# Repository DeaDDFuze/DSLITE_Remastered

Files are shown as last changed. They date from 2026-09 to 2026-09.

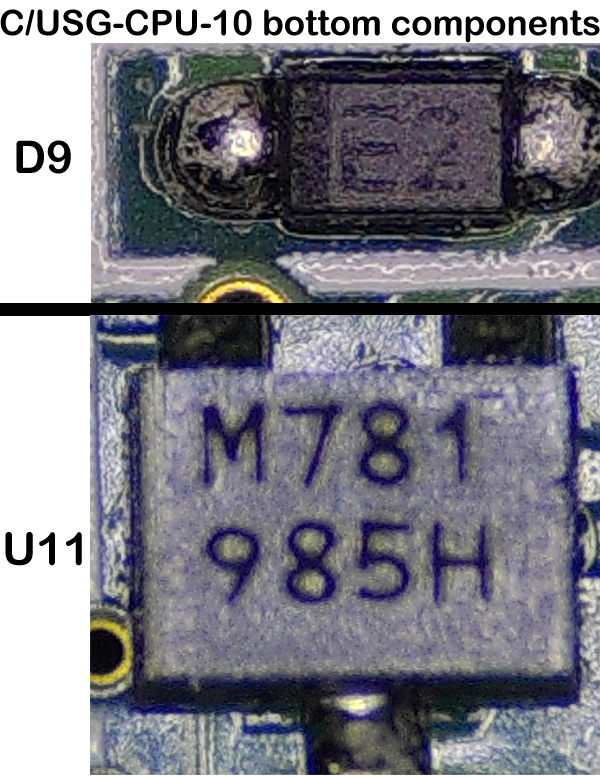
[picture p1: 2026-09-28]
docs/reverse-engineering/C-USG-CPU-10 components bottom.jpg

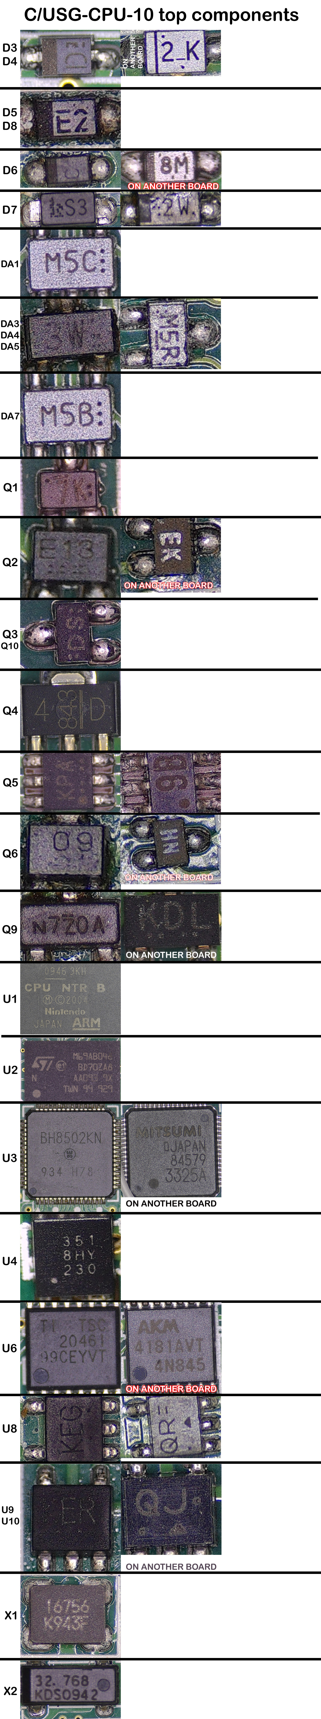
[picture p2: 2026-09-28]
docs/reverse-engineering/C-USG-CPU-10 components top.jpg

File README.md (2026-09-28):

# DSLITE_Remastered

> A modern hardware rework of the Nintendo DS Lite.

**DSLITE_Remastered** is an experimental hardware engineering project aiming to recreate and modernize the Nintendo DS Lite while preserving compatibility with the original console, cartridges, controls and overall form factor.

The goal is not to emulate a Nintendo DS on a modern computer.

The goal is to understand the original hardware, reverse-engineer it where necessary, redesign selected parts of the electronics, and progressively build a **modernized DS Lite around the original architecture**.

---

## Project goals

DSLITE_Remastered explores several areas of console hardware modernization:

- Reverse engineering of the Nintendo DS Lite motherboard
- Recreation of schematics in KiCad
- PCB analysis and eventual PCB redesign
- Replacement of ageing or obsolete components
- USB-C charging
- Modern battery and charging circuitry
- Improved power management
- Modern replacement displays
- Experimental display scaling / image processing
- Replacement shells and mechanical parts
- 3D CAD reconstruction of the console
- Improved repairability
- Hardware documentation
- Community-friendly component libraries

The project will remain modular so individual modifications can potentially be reproduced independently.

---

## Project philosophy

The idea behind DSLITE_Remastered is simple:

**repair, understand, reproduce, improve.**

Rather than replacing the entire console with a Raspberry Pi or an emulator, this project attempts to retain as much of the original Nintendo DS architecture as possible.

Whenever possible, the project will favor:

- original hardware compatibility;
- measurable and documented modifications;
- replaceable components;
- open design files;
- commonly available parts;
- reproducible modifications;
- preservation of the original console's behaviour.

Some parts of the project will necessarily remain experimental.

---

## Planned architecture

The long-term project may include several independent hardware modules.

### Main motherboard

Reverse engineering and recreation of the Nintendo DS Lite motherboard.

Current reference board:

`USG-CPU-10`

Objectives:

- reproduce the original schematic;
- identify component functions;
- document power rails;
- document buses and signals;
- recreate footprints;
- compare component revisions;
- prepare a possible redesigned motherboard.

---

### Power system

Potential improvements:

- USB-C connector;
- USB-C charging;
- modern Li-ion / Li-Po battery support;
- improved battery protection;
- improved charging controller;
- voltage monitoring;
- replaceable battery design.

USB Power Delivery is not currently required for the console but may be investigated for future accessories or docking concepts.

---

### Displays

One of the major experimental areas of the project.

Possible directions include:

- modern IPS LCD replacements;
- custom LCD interface boards;
- OLED experimentation;
- improved brightness;
- improved viewing angles;
- replacement backlight circuitry.

The native Nintendo DS resolution remains:

**256 × 192 pixels per screen**

A future experimental display controller may investigate integer scaling or real-time upscaling to higher-resolution panels.

---

## DS Remastered display concept

A more experimental branch of the project explores the concept of a **"DS Remastered" display pipeline**.

Instead of modifying the game software, a dedicated video-processing circuit could intercept the original display signal and process it before sending it to a modern panel.

Conceptually:

```text
Nintendo DS GPU
      │
      ▼
Original display signal
      │
      ▼
Video capture / interface
      │
      ▼
FPGA / video processor
      │
      ├── Integer scaling
      ├── Filtering
      ├── Pixel reconstruction
      └── Experimental upscaling
      │
      ▼
Modern LCD / OLED panel
```

The first realistic objective would be **clean integer scaling**, not AI-based reconstruction.

More advanced processing may be investigated later.

---

## Mechanical redesign

The mechanical side of the project will be developed primarily using **Fusion 360**.

Possible work includes:

- recreation of the DS Lite shell;
- internal mounting points;
- USB-C modifications;
- display adapters;
- replacement hinge mechanisms;
- battery compartment redesign;
- custom shells;
- prototype PCBs;
- 3D printable replacement parts.

KiCad remains the primary tool for electronic design.

---

## Software used

### Electronics

- KiCad
- SPICE simulation where appropriate
- Datasheets
- Multimeter
- Logic analyser
- Oscilloscope

### Mechanical design

- Autodesk Fusion 360
- Mesh / STEP / STL tools
- 3D printing

### Development / documentation

- Git
- GitHub
- Linux
- Markdown
- Python

---

## Repository structure

The repository will progressively follow a structure similar to:

```text
DSLITE_Remastered/
│
├── README.md
├── LICENSE
│
├── docs/
│   ├── architecture/
│   ├── reverse-engineering/
│   ├── measurements/
│   └── research/
│
├── datasheets/
│
├── schematic/
│   ├── original/
│   └── remastered/
│
├── pcb/
│   ├── original/
│   └── remastered/
│
├── libraries/
│   ├── symbols/
│   ├── footprints/
│   └── 3dmodels/
│
├── mechanical/
│   ├── shell/
│   ├── screen/
│   └── usb-c/
│
├── firmware/
│
├── tools/
│
└── references/
```

This structure may change as the project evolves.

---

## Current project status

**Status: Research / Reverse Engineering**

Current work focuses on:

- collecting DS Lite motherboard documentation;
- analysing the `USG-CPU-10` board revision;
- identifying components;
- collecting datasheets;
- reconstructing schematics;
- creating reusable KiCad symbols and footprints;
- preparing a clean Git repository structure.

No complete replacement motherboard exists yet.

---

## Roadmap

### Phase 1 — Documentation

- [ ] Photograph and document the motherboard
- [ ] Identify major ICs
- [ ] Identify passive components
- [ ] Collect datasheets
- [ ] Document test points
- [ ] Document connectors
- [ ] Map power rails

### Phase 2 — Schematic reconstruction

- [ ] Recreate `USG-CPU-10` schematics
- [ ] Verify connections
- [ ] Create missing KiCad symbols
- [ ] Create missing footprints
- [ ] Compare board revisions

### Phase 3 — PCB reconstruction

- [ ] Recreate PCB outline
- [ ] Position major components
- [ ] Reconstruct routing
- [ ] Validate dimensions
- [ ] Generate 3D PCB model

### Phase 4 — Modernization

- [ ] USB-C charging
- [ ] Modern battery circuitry
- [ ] Modern replacement displays
- [ ] Improved power circuitry
- [ ] Replacement shell design

### Phase 5 — DS Remastered experiments

- [ ] Capture original LCD signals
- [ ] Characterize timing
- [ ] Prototype FPGA display interface
- [ ] Integer-scale DS output
- [ ] Test higher-resolution panels
- [ ] Investigate image enhancement

### Phase 6 — Prototype

- [ ] Manufacture prototype PCBs
- [ ] Assemble board
- [ ] Power validation
- [ ] Boot testing
- [ ] Cartridge testing
- [ ] Touchscreen testing
- [ ] Wireless testing
- [ ] Long-term reliability testing

---

## Reverse engineering notes

All measurements and reverse-engineering information should be documented whenever possible.

Useful information includes:

```text
Component reference
Manufacturer
Part number
Package
Measured value
Connected signals
Voltage
Frequency
Datasheet
Board location
Notes
```

This repository should progressively become both a development repository and a technical reference for DS Lite hardware.

---

## KiCad libraries

One objective of the project is to create a reusable local KiCad library for DS Lite components.

Example:

```text
libraries/
├── symbols/
│   └── DSLITE_Remastered.kicad_sym
│
├── footprints/
│   └── DSLITE_Remastered.pretty/
│
└── 3dmodels/
    ├── STEP/
    └── WRL/
```

Components should preferably include:

- symbol;
- footprint;
- datasheet reference;
- manufacturer part number;
- package;
- pin description;
- 3D model when available.

---

## Contributions

Contributions are welcome.

Useful contributions include:

- board photographs;
- high-resolution scans;
- component identification;
- datasheets;
- PCB measurements;
- schematics;
- KiCad symbols;
- KiCad footprints;
- 3D models;
- electrical measurements;
- compatible replacement components;
- repair documentation.

Please document the source of technical information whenever possible.

---

## Disclaimer

DSLITE_Remastered is an independent, unofficial hardware research project.

Nintendo, Nintendo DS, Nintendo DS Lite and related trademarks are property of Nintendo and their respective owners.

This project is not affiliated with, endorsed by, or sponsored by Nintendo.

The repository is intended for:

- hardware research;
- repair;
- preservation;
- reverse engineering;
- education;
- experimentation.

No proprietary Nintendo software, firmware, ROMs or copyrighted game assets should be distributed through this repository.

---

## License

The final licensing model has not yet been selected.

Because the project may contain hardware designs, documentation and software, separate licenses may eventually be used for each category.

Possible choices include:

- CERN Open Hardware Licence for PCB and hardware designs
- GPL or MIT for software and tools
- Creative Commons for documentation

---

## Project name

**DSLITE_Remastered**

Experimental Nintendo DS Lite hardware modernization and preservation project.

```text
Original hardware.
Modern components.
Same DS.
```

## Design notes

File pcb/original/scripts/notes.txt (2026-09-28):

2 vias are missing from the vdd plane. but they are present on the vias script. one is near a hole in the left side of the board. and the other is close to the vdd1.2 plane (where the scan is scratched).

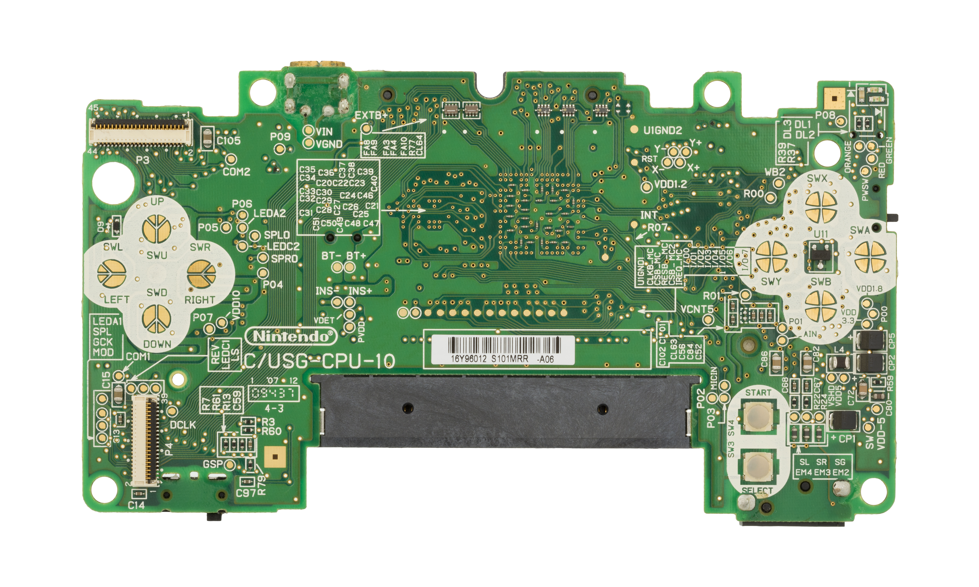
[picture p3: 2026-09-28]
docs/reverse-engineering/wikipedia bottom.jpg

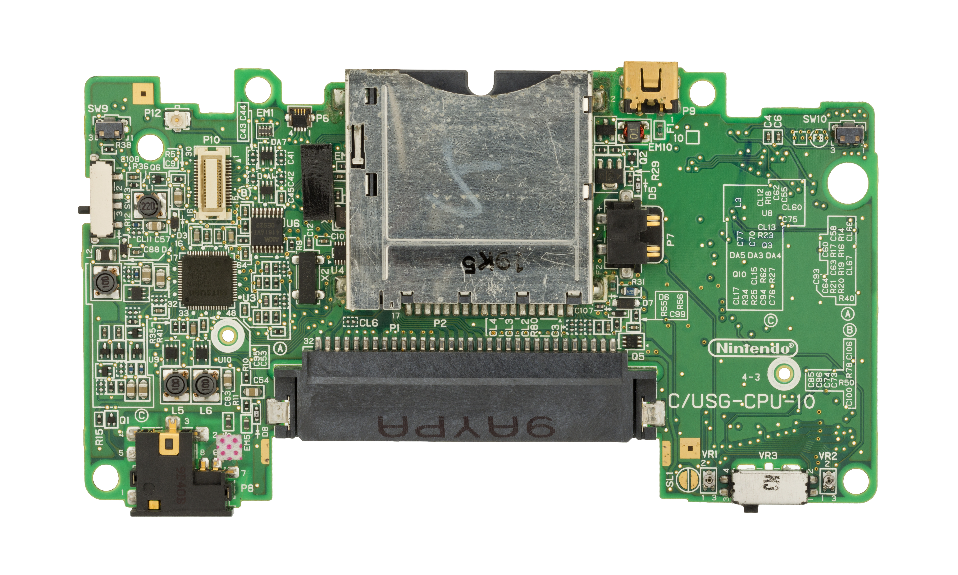
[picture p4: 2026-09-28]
docs/reverse-engineering/wikipedia top.jpg

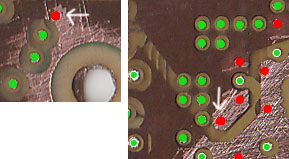
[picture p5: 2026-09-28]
pcb/original/scripts/notes.jpg

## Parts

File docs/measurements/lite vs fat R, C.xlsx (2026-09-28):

Lite(C/USG-CPU-10) | Fat(C/NTR-CPU-10)
TOP
R31-(MARKED R634) | R31=(MARKED R910) |  | between INS+ and INS-
R36-100K | R36=198.2K |  | power switch pullup
.--- | R51=675R
R78-1K | .---
R80-100R | .---
R60-2.2K | R60=2.7K | lite is on the bottom | VR1 to gnd (top screen)
R61-2.2K | R61=2.7K | lite is on the bottom | VR2 to gnd (bottom screen)
.--- | R63=20K
.--- | R66=200k
.--- | R67=100K
.--- | R68=55.9K
.--- | R69=5K
.--- | R70=5K
C55-11UF | C55=5.8UF | fat is on the bottom | B+ to gnd
C52-100NF | C52=1.2UF | lite is on the bottom | PMIC38 (AIN)
C56-100NF | C56=1.2UF | lite is on the bottom | B+ to gnd
.--- | C65=5.8UF
C73-5UF | C73=10UF |  | EXTB+ to gnd
.--- | C78=1.2UF
C83-10UF | C83=5.8UF |  | B+ (LEDA1 area)
.--- | C87=5.8UF
C106-1.1NF | .---
C107-0.13NF | .---
C108-100NF | .---
BOTTOM
R3-32.8K | R3=20K |  | VR1 to VDD5 (top screen)
R7-32.7K | R7=20K |  | VR2 to VDD5 (bottom screen)
.--- | R26=510K
.--- | R32=10R
.--- | R33=100K
.--- | R45=100K
.--- | R46=100K
.--- | R47=100K
.--- | R48=200K
.--- | R49=200K
.--- | R53=100R
.--- | R54=100R
R79-10K | .---
.--- | C8=100NF
.--- | C35=100NF
.--- | C61=5.8UF
.--- | C66=100NF
.--- | C71=2.4UF
.--- | C79=100NF
.--- | C81=2.4UF
.--- | C89=2.5UF
.--- | C90=2.4UF
.--- | C91=10UF
.--- | C92=100NF
C101-100NF | .---
C102-100NF | .---
C105-11UF | .---

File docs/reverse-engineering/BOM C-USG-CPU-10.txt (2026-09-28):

The donor board was in perfect working condition. C/USG-CPU-10

TOP COMPONENTS (THE SIDE WITH THE CPU)
R1-1.5M
R2-2.2K
R5-100K
R9-57.2K
R10-2.2K
R11-2.2K
R12-0R???
R14-47K
R15-1M
R16-47K
R17-47K
R18-0R???
R19-47K
R20-46.2K
R21-46.7K
R23-0R???
R25-500K
R27-0.8R
R28-676R
R29-500K
R30-240R
R31-0R??? (MARKED R634)
R34-1M
R35-33.3R
R36-100K
R38-1.3K
R40-10K
R41-33.3R
R50-10R
R55-200K
R56-100K
R62-0.8R
R65-55.2R
R78-1K
R80-100R
C1-TO LOW TO MEASURE
C2-TO LOW TO MEASURE
C3-1.1UF
C4-100NF
C5-1.1UF
C6-100NF
C9-10UF
C10-100NF
C11-100NF
C12-TO LOW TO MEASURE
C17-1.1UF
C45-1.1UF
C53-1UF
C54-11UF
C55-11UF
C57-23UF
C58-0.140NF
C60-0.56NF
C62-23UF
C63-0.135NF
C64-0.56NF
C70-100NF
C73-5UF
C74-1.1UF
C75-1.2UF
C76-10UF
C77-100NF
C83-10UF
C85-5UF
C88-100NF
C93-1.1UF
C94-10UF
C95-2.5UF
C96-100NF
C99-100NF
C100-100NF
C106-1.1NF
C107-0.13NF
C108-100NF
L1-0.02MH
L2-0.03MH
L3, L5, L6-0.01MH

cl2.3,4,5,6,9,11,12,13,15,17, 60,65,67,68 closed

BOTTOM COMPONENTS
R3-32.8K
R7-32.7K
R13-3K
R22-55.3R
R24-56R
R37-1.3K
R39-1.1K
R59-200K
R60-2.2K
R61-2.2K
R79-10K
C13-100NF
C14-100NF
C15-11UF
C52-100NF
C56-100NF
C59-100NF
C67-100NF
C68-100NF
C72-2.3UF
C80-1UF
C82-1UF
C84-100NF
C86-1UF
C97-100NF
C101-100NF
C102-100NF
C105-11UF
UNDER CPU: C20...C40, C46...C51 ALL ARE 100NF
CP1, CP2, CP5-100UF
L4-0.03MH

cl 63, 64 closed

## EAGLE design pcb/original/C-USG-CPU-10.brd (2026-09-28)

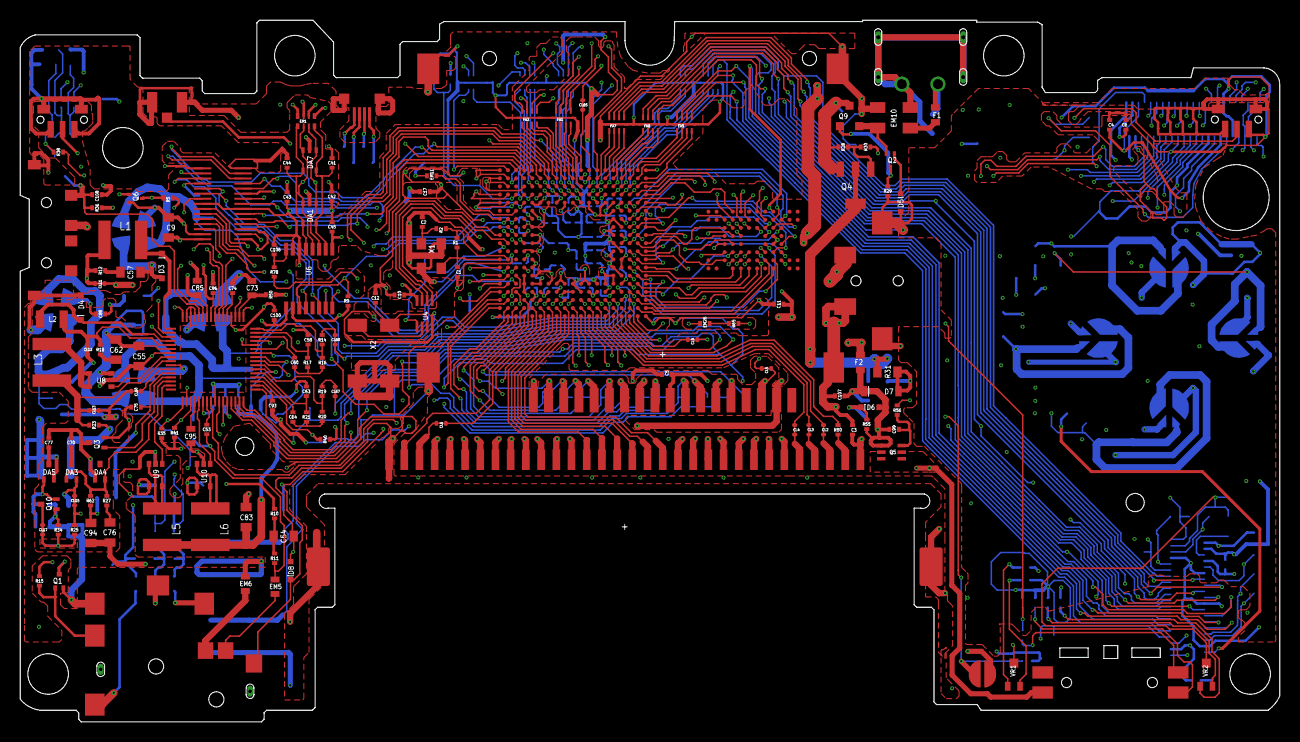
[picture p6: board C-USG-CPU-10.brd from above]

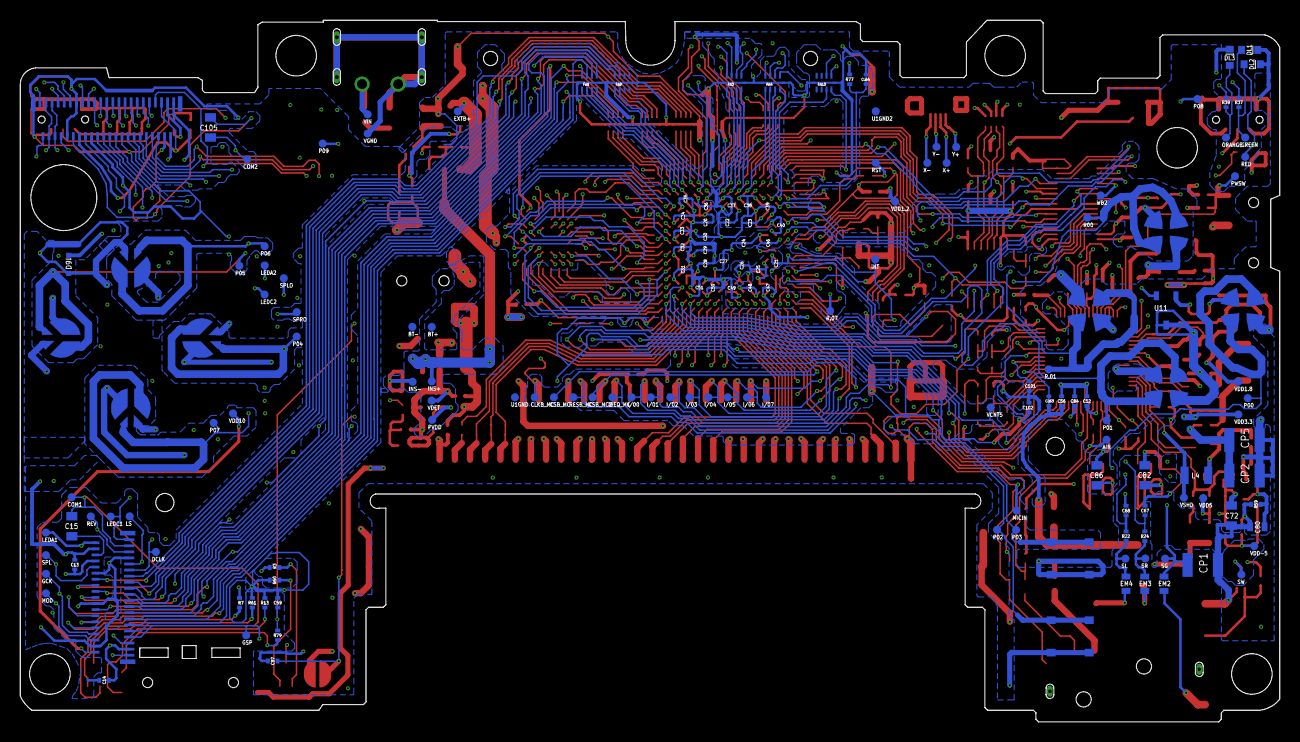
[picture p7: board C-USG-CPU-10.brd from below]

Board: 6 copper layers, 124.3 x 69.2 mm, 319 parts (164 on the bottom side), 328 nets.

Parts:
AIN: TP
BT+: TP
BT-: TP
BUT_A: BUT_ABXY; BUTTONSABXY
BUT_B: BUT_ABXY; BUTTONSABXY
BUT_L: SHOULDER_BUT
BUT_R: SHOULDER_BUT
BUT_X: BUT_ABXY; BUTTONSABXY
BUT_Y: BUT_ABXY; BUTTONSABXY
C1, C2, C3, C4, C5, C6, C10, C11, C12, C13, C14, C17, C41, C42, C43, C44, C45, C52, C53, C56, C58, C59, C60, C63, C64, C67, C68, C70, C74, C75, C77, C84, C88, C93, C96, C97, C99, C100, C101, C102, C106, C107, C108: C0402; 0402
C9, C15, C54, C55, C57, C62, C72, C76, C82, C83, C86, C94, C105: C0805; 0805
C20, C21, C22, C23, C24, C25, C26, C27, C28, C29, C30, C31, C32, C33, C34, C35, C36, C37, C38, C39, C40, C46, C47, C48, C49, C50, C51: C0201; 0201
C73, C80, C85, C95: C0603; 0603
CL2, CL3, CL4, CL5, CL6, CL9, CL11, CL12, CL13, CL15, CL17, CL60, CL63, CL64, CL65, CL67, CL68: CL; CL0402
CLKB_MC: TP
COM1, COM2: TP
CP1, CP2, CP5: CP
CSB_MC, CSB_MC2: TP
D3, D4: D3.4
D5, D9: D5
D6: D6
D7: D7
D8: D8
DA1: MA5J002D; DA
DA3, DA4, DA5: MA3SD29F
DA7: MA5J002E; DA
DCLK: TP
DL1, DL2, DL3: DL
DOWN: DPAD
EM1: FILTER_NETWORK
EM2, EM3, EM4, EM5, EM6: FILTER0603; 0603
EM10: EM10
EM11, EM26: FILTER; 0402
EXTB+: TP
F1, F2: FUSE
FA1, FA2, FA3, FA4, FA5, FA6, FA7, FA8, FA9, FA10: FA
GCK: TP
GREEN: TP
GSP: TP
I/00, I/01, I/02, I/03, I/04, I/05, I/06, I/07: TP
INS+: TP
INS-: TP
INT: TP
IREQ_MC: TP
L1, L3, L5, L6: INDUCTOR
L2, L4: INDUCTOR_SMALL
LEDA1, LEDA2: TP
LEDC1, LEDC2: TP
LEFT: DPAD
LS: TP
MICIN: TP
MOD: TP
ORANGE: TP
P00, P01, P02, P03, P04, P05, P06, P07, P08, P09: TP
P.1: GBASLOT; GBA
P.2: DSSLOT; DS
P.3: TOP_SCR+SPK
P.4: BOTTOM_SCREEN
P.6: TOUCH; P6
P.7: BAT
P.8: HEADPHONES
P.9: CHARGEPORT
P.10: DWM-W006; DWM--W006
P.12: MIC
PVDD: TP
PWSW: TP
Q1: Q1
Q2: DTA143ZM; SOT723
Q3, Q10: SSM3K16FS; Q3.10
Q4: 2SA2069; SOT89-3
Q5: SSM6J21TU; UF6
Q6: 2SC4244; SOT723
Q9: SSM3J14T; TO236
R00, R.01, R.07: TP
R1, R2, R3, R5, R7, R9, R10, R11, R12, R13, R14, R15, R16, R17, R18, R19, R20, R21, R22, R23, R24, R25, R27, R28, R29, R30, R34, R35, R36, R37, R38, R39, R40, R41, R50, R55, R56, R59, R60, R61, R62, R65, R77, R78, R79, R80: R0402; 0402
R31: R0805; 0805
RED: TP
RESB_MC: TP
REV: TP
RIGHT: DPAD
RST: TP
SELECT: BUTTON_SMALL
SG: TP
SL: TP
SL1: SL1
SPL: TP
SPLO: TP
SPRO: TP
SR: TP
START: BUTTON_SMALL
SW: TP
SW13: SWITCH
U1: NTR_CPU_B; CPU
U1GND, U1GND2: TP
U2: 82DBS02163C-70L; RAM
U3: MITSUMI_3325A
U4: RTC; TSSOP8
U6: TSC2046; TSSOP16
U8: SSM5G04TU; SOT-353F___(UFV)-M
U9, U10: SSM5H08TU; SOT-353F___(UFV)-M
U11: EM6781
UP: DPAD
VCNT5: TP
VDD1.2, VDD1.8, VDD3.3, VDD5, VDD10: TP
VDD-5: TP
VDET: TP
VGND: TP
VIN: TP
VR1, VR2: VR
VR3: VOLUME
VSHD: TP
WB2: TP
X1: X1
X2: X2
X+: TP
X-: TP
Y+: TP
Y-: TP

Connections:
A16: P.1.22, U1.G17
A17: P.1.23, U1.H17
A18: P.1.24, U1.I17
A19: P.1.25, U1.J17
A20: P.1.26, U1.K17
A21: P.1.27, U1.L17
A22: P.1.28, U1.M17
A23: P.1.29, U1.N17
AD0: P.1.6, U1.G18
AD1: P.1.7, U1.G19
AD2: P.1.8, U1.H18
AD3: P.1.9, U1.H19
AD4: P.1.10, U1.I18
AD5: P.1.11, U1.I19
AD6: P.1.12, U1.J18
AD7: P.1.13, U1.J19
AD8: P.1.14, U1.K18
AD9: P.1.15, U1.K19
AD10: P.1.16, U1.L18
AD11: P.1.17, U1.L19
AD12: P.1.18, U1.M18
AD13: P.1.19, U1.M19
AD14: P.1.20, U1.N18
AD15: P.1.21, U1.N19
AIN: AIN.P$1, C53.2, EM5.1, R11.2
AUX: R78.1, U3.40
B+: C55.1, C56.2, C83.1, CL63.1, CL63.2, L5.P$2, L6.P$2, Q5.1, Q5.2, Q5.5, Q5.6, U3.16, U3.19, U3.23, U3.55, U8.2, VR3.3
B.B0: FA6.1, P.4.22
B.B1: FA7.7, P.4.23
B.B2: FA7.5, P.4.24
B.B3: FA7.3, P.4.25
B.B4: FA7.1, P.4.26
B.B5: FA9.3, P.4.27
B.G0: FA8.7, P.4.15
B.G1: FA6.5, P.4.16
B.G2: FA6.7, P.4.17
B.G3: FA8.5, P.4.19
B.G4: FA9.1, P.4.20
B.G5: FA6.3, P.4.21
B.R0: FA8.3, P.4.9
B.R1: FA8.1, P.4.10
B.R2: FA5.7, P.4.11
B.R3: FA5.3, P.4.12
B.R4: FA5.5, P.4.13
B.R5: FA5.1, P.4.14
BT+: BT+.P$1, F2.1, P.7.+
CLKB_MC: CL5.1, CL5.2, CLKB_MC.P$1, P.2.2, U1.T16
COM1: C15.1, COM1.P$1, P.4.37, VR2.2
COM2: C105.1, COM2.P$1, P.3.37, VR1.2
CS1B: CL4.1, CL4.2, P.1.5, U1.F19
CS2B: CL6.1, CL6.2, P.1.30, U1.O18
CSB_MC: CSB_MC.P$1, P.2.4, U1.S17
CSB_MC2: CSB_MC2.P$1, P.2.6, U1.P17
DCLK: DCLK.P$1, P.3.29, P.4.29, U1.G1
EXTB+: EXTB+.P$1, Q4.3, Q9.3, R28.1, R50.1
GCK: GCK.P$1, P.3.8, P.4.8, U1.H3
GND: BT-.P$1, BUT_A.1, BUT_A.4, BUT_B.1, BUT_B.4, BUT_L.1, BUT_L.3, BUT_L.S1, BUT_L.S2, BUT_R.1, BUT_R.3, BUT_R.S1, BUT_R.S2, BUT_X.1, BUT_X.4, BUT_Y.1, BUT_Y.4, C1.1, C2.2, C3.2, C4.2, C5.2, C6.1, C9.2, C10.2, C11.1, C12.1, C13.2, C14.2, C17.2, C20.2, C21.2, C22.2, C23.2, C24.2, C25.2, C26.2, C27.2, C28.2, C29.2, C30.2, C31.2, C32.2, C33.2, C34.2, C35.2, C36.2, C37.2, C38.2, C39.2, C40.2, C41.1, C42.1, C43.1, C44.1, C45.1, C46.2, C47.2, C48.2, C49.2, C50.2, C51.2, C52.2, C54.2, C55.2, C56.1, C57.2, C58.2, C59.1, C62.2, C63.2, C67.2, C68.2, C72.1, C73.1, C74.1, C75.1, C76.2, C80.2, C82.1, C83.2, C84.1, C85.1, C86.1, C88.2, C93.1, C94.2, C95.1, C96.1, C97.1, C100.1, C101.2, C102.2, C106.1, C107.1, C108.1, CL64.1, CL64.2, CP1.1, CP2.1, CP5.1, D3.A, D4.A, D5.A, D8.A, D9.A, DA1.2, DA5.2, DL1.C, DL2.C, DL3.C, DOWN.1, DOWN.4, EM6.1, EM10.3, FA1.G1, FA1.G2, FA2.G1, FA2.G2, FA3.G1, FA3.G2, FA4.G1, FA4.G2, FA5.G1, FA5.G2, FA6.G1, FA6.G2, FA7.G1, FA7.G2, FA8.G1, FA8.G2, FA9.G1, FA9.G2, FA10.G1, FA10.G2, LEFT.1, LEFT.4, P.1.32, P.1.S1, P.1.S2, P.2.1, P.2.17, P.2.S1, P.2.S2, P.2.S3, P.2.S4, P.3.4, P.3.18, P.3.28, P.3.33, P.3.36, P.3.S2, P.4.4, P.4.18, P.4.28, P.4.33, P.4.36, P.6.S1, P.6.S2, P.7.-, P.7.S1, P.7.S2, P.8.4, P.10.1, P.10.6, P.10.9, P.10.13, P.10.15, P.10.17, P.10.23, P.10.30, P.12.G1, P.12.G2, Q1.2, Q3.2, Q6.2, Q10.1, R13.1, R29.2, R34.2, R35.2, R41.1, R59.2, R60.1, R61.1, R77.2, RIGHT.1, RIGHT.4, SELECT.2, SELECT.3, START.2, START.3, SW13.2, SW13.S1, SW13.S2, U1.A1, U1.A19, U1.D8, U1.D11, U1.D14, U1.E5, U1.E7, U1.E10, U1.E13, U1.F16, U1.G5, U1.G15, U1.I16, U1.J5, U1.J15, U1.L16, U1.M5, U1.M15, U1.O8, U1.O11, U1.O14, U1.O16, U1.O17, U1.P5, U1.P8, U1.P11, U1.P13, U1.R4, U1.R5, U1.R6, U1.S2, U1.S4, U1.S5, U1.T1, U1.T4, U1.T5, U1.T19, U1GND.P$1, U1GND2.P$1, U2.G2, U2.J8, U3.4, U3.13, U3.14, U3.15, U3.22, U3.26, U3.34, U3.41, U3.60, U4.4, U6.6, U6.7, U8.3, U9.2, U10.2, U11.3, UP.1, UP.4, X1.2, X1.4, X2.2, X2.3
GREEN: DL1.A, GREEN.P$1, R37.2
GSP: GSP.P$1, P.3.7, P.4.7, U1.H4
I/O0: I/00.P$1, P.2.9, U1.T17
I/O1: I/01.P$1, P.2.10, U1.T18
I/O2: I/02.P$1, P.2.11, U1.S18
I/O3: I/03.P$1, P.2.12, U1.S19
I/O4: I/04.P$1, P.2.13, U1.R18
I/O5: I/05.P$1, P.2.14, U1.R19
I/O6: I/06.P$1, P.2.15, U1.P18
I/O7: I/07.P$1, P.2.16, U1.P19
INS+: INS+.P$1, Q4.2, Q4.P, R31.2, U3.7
INS-: D7.A, INS-.P$1, R31.1, U3.8
INT: INT.P$1, U1.T10, U4.1
IREQ_MC: IREQ_MC.P$1, P.2.7, U1.R17
IRQ: P.1.31, U1.O19
LEDA1: C82.2, LEDA1.P$1, P.4.38, U9.4
LEDA2: C86.2, LEDA2.P$1, P.3.38, U10.4
LEDC1: LEDC1.P$1, P.4.39, R35.1, U3.33
LEDC2: D9.C, LEDC2.P$1, P.3.39, R41.2, U3.35
LS: LS.P$1, P.3.31, P.4.31, U1.H2
MICIN: D8.C, MICIN.P$1, P.8.7, P.12.M
MOD: MOD.P$1, P.3.6, P.4.6, U1.I2
unnamed: P.8.5, Q1.1, R15.1
unnamed: C95.2, U3.36
unnamed: C99.2, Q5.3, R56.1
unnamed: C70.2, DA3.3
unnamed: Q6.1, U11.2
unnamed: U1.B15, U2.G1
unnamed: C74.2, U3.5
unnamed: U1.C14, U2.F1
unnamed: C77.2, DA5.3
unnamed: C62.1, R18.2
unnamed: U1.A14, U2.E1
unnamed: EM3.2, P.8.3
unnamed: EM4.2, P.8.2
unnamed: R9.1, U1.R9, U6.11
unnamed: C67.1, R24.1, U3.56
unnamed: C68.1, R22.1, U3.59
unnamed: U1.B13, U2.D1
unnamed: R37.1, U3.43
unnamed: U1.C12, U2.F2
unnamed: U1.A12, U2.E2
unnamed: U1.C11, U2.D2
unnamed: U1.B10, U2.C2
unnamed: R56.2, U3.11
unnamed: U1.A10, U2.C6
unnamed: C58.1, R17.1, U3.63
unnamed: U1.C9, U2.E6
unnamed: C64.1, U3.52
unnamed: U1.A8, U2.F6
unnamed: FA8.4, U1.D3
unnamed: U1.E17, U6.15
unnamed: C93.2, U3.50
unnamed: U1.T9, U4.7
unnamed: C42.2, DA1.1, DA7.1, EM1.6, U6.3
unnamed: U1.C8, U2.C7
unnamed: U1.B7, U2.D7
unnamed: R80.1, U1.E18
unnamed: U4.2, X2.1
unnamed: C106.2, R78.2, U6.8
unnamed: C43.2, DA1.3, DA7.3, EM1.4, U6.4
unnamed: C44.2, DA1.4, DA7.4, EM1.2, U6.5
unnamed: U1.S10, U4.6
unnamed: C41.2, DA1.5, DA7.5, EM1.8, U6.2
unnamed: U1.R10, U4.5
unnamed: C12.2, U4.3, X2.4
unnamed: R1.1, R2.2, U1.S12
unnamed: C1.2, R1.2, U1.T12, X1.3
unnamed: P.10.29, U1.P1
unnamed: C2.1, R2.1, X1.1
unnamed: P.10.21, U1.P2
unnamed: P.10.19, U1.R1
unnamed: P.10.2, U1.O2
unnamed: P.10.3, U1.N3
unnamed: P.10.4, U1.N4
unnamed: P.10.5, U1.N2
unnamed: P.10.7, U1.N1
unnamed: U1.A6, U2.E7
unnamed: P.10.8, U1.O1
unnamed: U1.A5, U2.F7
unnamed: P.10.20, U1.L2
unnamed: U1.A4, U2.D8
unnamed: U1.C5, U2.G8
unnamed: U1.A3, U2.F3
unnamed: U1.B4, U2.E3
unnamed: U1.B3, U2.D6
unnamed: C63.1, R21.1, U3.53
unnamed: U1.C4, U2.E5
unnamed: U1.C3, U2.E8
unnamed: U1.A15, U2.J2
unnamed: EM10.2, F1.1
unnamed: Q2.3, Q9.1, R29.1
unnamed: C52.1, R10.1, U3.38
unnamed: U1.B14, U2.G3
unnamed: U1.A13, U2.K3
unnamed: P.10.10, U1.M4
unnamed: C70.1, C77.1, DA4.1, L4.2, Q3.3
unnamed: FA8.2, U1.D4
unnamed: P.10.11, U1.M2
unnamed: P.10.18, U1.M1
unnamed: U1.C13, U2.H4
unnamed: P.10.12, U1.L3
unnamed: C73.2, R50.2, U3.2
unnamed: P.10.14, U1.M3
unnamed: EM11.2, U1.T7
unnamed: FA5.8, U1.A2
unnamed: U1.B12, U2.H5
unnamed: FA5.4, U1.B1
unnamed: FA5.6, U1.B2
unnamed: FA5.2, U1.C2
unnamed: U1.B11, U2.K6
unnamed: FA8.8, U1.E3
unnamed: FA6.6, U1.D2
unnamed: U1.A11, U2.G6
unnamed: FA6.8, U1.C1
unnamed: FA8.6, U1.E4
unnamed: FA9.2, U1.F3
unnamed: R39.1, U3.3
unnamed: U1.C10, U2.J7
unnamed: FA6.4, U1.D1
unnamed: C54.1, R10.2, R11.1
unnamed: U1.B9, U2.K2
unnamed: Q3.1, U3.29
unnamed: C53.1, U3.39
unnamed: U1.A9, U2.H3
unnamed: U1.B8, U2.J3
unnamed: U1.A7, U2.K4
unnamed: C64.2, R20.1, R21.2
unnamed: U1.C7, U2.J6
unnamed: FA6.2, U1.E2
unnamed: FA7.8, U1.E1
unnamed: FA7.6, U1.F2
unnamed: FA7.4, U1.F1
unnamed: FA7.2, U1.G2
unnamed: FA9.4, U1.G3
unnamed: FA1.8, U1.I1
unnamed: FA1.6, U1.I3
unnamed: FA3.2, U1.I4
unnamed: R13.2, VR3.1
unnamed: U1.B6, U2.H6
unnamed: U1.C6, U2.K7
unnamed: D5.C, Q2.1
unnamed: EM10.1, Q2.2, Q9.2
unnamed: Q4.1, R28.2, R30.2
unnamed: U1.B5, U2.H7
unnamed: FA1.2, U1.J2
unnamed: U1.B18, U2.J1
unnamed: C59.2, R79.1, U3.61
unnamed: FA1.4, U1.J1
unnamed: U1.B17, U2.D5
unnamed: U1.A18, U2.H2
unnamed: U1.B16, U2.C5
unnamed: U1.A17, U2.C3
unnamed: U1.A16, U2.D3
unnamed: FA3.4, U1.J3
unnamed: FA3.6, U1.J4
unnamed: FA2.2, U1.K4
unnamed: FA2.8, U1.K1
unnamed: FA2.6, U1.K2
unnamed: U1.C15, U2.D4
unnamed: EM26.1, U1.C16
unnamed: EM26.2, R65.1
unnamed: R65.2, U2.C4
unnamed: FA3.8, U1.K3
unnamed: FA4.2, U1.L4
unnamed: FA2.4, U1.L1
unnamed: R7.1, VR2.1
unnamed: FA4.4, U1.O3
unnamed: FA4.6, U1.O4
unnamed: FA10.6, U1.R2
unnamed: FA10.8, U1.S1
unnamed: FA4.8, U1.P4
unnamed: C15.2, P.4.34
unnamed: R61.2, VR2.3
unnamed: R3.1, VR1.1
unnamed: C105.2, P.3.34
unnamed: R60.2, VR1.3
unnamed: R19.1, R20.2, U3.54
unnamed: CL67.1, CL67.2, R19.2, U1.D16
unnamed: C60.2, R16.1, R17.2
unnamed: C60.1, U3.62
unnamed: R14.1, R16.2, U3.64
unnamed: CL68.1, CL68.2, R14.2, U1.D17
unnamed: R79.2, VR3.2
unnamed: U3.31, U9.1
unnamed: U3.37, U10.1
unnamed: L5.P$1, U9.3, U9.5
unnamed: R38.1, U3.42
unnamed: L6.P$1, U10.3, U10.5
unnamed: EM6.2, P.8.8
unnamed: EM5.2, P.8.6
unnamed: R30.1, U3.6
unnamed: C80.1, DA5.1, Q10.2, R59.1
unnamed: DA3.1, DA4.2, R27.1, R62.1, U3.30
unnamed: C76.1, R27.2
unnamed: L3.P$2, U8.4, U8.5
unnamed: CP2.2, CP5.2, R23.1
unnamed: U3.24, U8.1
unnamed: D4.C, L2.2, U3.20
unnamed: C57.1, R12.2
unnamed: D3.C, L1.P$2, U3.17
ORANGE: DL3.A, ORANGE.P$1, R39.2
P00: BUT_A.2, BUT_A.3, P00.P$1, U1.S16
P01: BUT_B.2, BUT_B.3, P01.P$1, U1.R15
P02: P02.P$1, SELECT.1, SELECT.4, U1.S15
P03: P03.P$1, START.1, START.4, U1.T15
P04: P04.P$1, RIGHT.2, RIGHT.3, U1.R14
P05: LEFT.2, LEFT.3, P05.P$1, U1.S14
P06: P06.P$1, U1.T14, UP.2, UP.3
P07: DOWN.2, DOWN.3, P07.P$1, U1.R13
P08: BUT_R.2, P08.P$1, U1.S13
P09: BUT_L.2, P09.P$1, U1.T13
PHI: P.1.2, R80.2
PHONES.GND: EM2.2, P.8.1
PVDD: C10.1, C85.2, D6.C, PVDD.P$1, R36.1, R55.1, U3.10, U4.8
PWSW: C108.2, PWSW.P$1, R36.2, SW13.1, U3.12
R00: BUT_X.2, BUT_X.3, R00.P$1, U1.S7
R.01: BUT_Y.2, BUT_Y.3, R.01.P$1, U1.R7
R.07: Q6.3, R5.1, R.07.P$1, U1.B19, U1.S9
RDB: CL3.1, CL3.2, P.1.4, U1.F18
RED: DL2.A, R38.2, RED.P$1
RESB_MC: P.2.5, RESB_MC.P$1, U1.R16
REV: CL65.1, CL65.2, P.3.35, P.4.35, REV.P$1, U1.H1
RST: EM11.1, P.10.22, R40.1, RST.P$1, U3.51
SG: CP1.2, EM2.1, P.3.42, P.3.43, SG.P$1
SL: EM4.1, R22.2, SL.P$1
SPI_C1: U1.C18, U3.48
SPI_C2: P.10.28, U1.D18
SPI_MISO: P.10.26, U1.D19, U3.47, U6.12
SPI_MOSI: P.10.25, U1.F17, U3.46, U6.14
SPI_SK: CL9.1, CL9.2, P.10.24, U1.C19, U3.45, U6.16
SPL: P.3.30, P.4.30, SPL.P$1, U1.G4
SPLO: C102.1, P.3.44, P.3.45, SPLO.P$1, U3.58
SPRO: C101.1, P.3.40, P.3.41, SPRO.P$1, U3.57
SR: EM3.1, R24.2, SR.P$1
SW: Q1.3, SW.P$1, U3.1
T.B0: FA2.3, P.3.22
T.B1: FA4.3, P.3.23
T.B2: FA4.5, P.3.24
T.B3: FA10.5, P.3.25
T.B4: FA10.7, P.3.26
T.B5: FA4.7, P.3.27
T.G0: FA3.5, P.3.15
T.G1: FA2.1, P.3.16
T.G2: FA2.7, P.3.17
T.G3: FA2.5, P.3.19
T.G4: FA3.7, P.3.20
T.G5: FA4.1, P.3.21
T.R0: FA1.7, P.3.9
T.R1: FA1.5, P.3.10
T.R2: FA3.1, P.3.11
T.R3: FA1.1, P.3.12
T.R4: FA1.3, P.3.13
T.R5: FA3.3, P.3.14
VCNT5: U1.C17, U3.49, VCNT5.P$1
VDD1.2: C17.1, C20.1, C21.1, C22.1, C23.1, C24.1, C25.1, C26.1, C27.1, C28.1, C29.1, C30.1, CL11.1, CL11.2, L1.P$1, R12.1, U1.E6, U1.E8, U1.E9, U1.E11, U1.E12, U1.E14, U1.E15, U1.F5, U1.F15, U1.H5, U1.H15, U1.I15, U1.K5, U1.K15, U1.L15, U1.N15, U1.O6, U1.O9, U1.O10, U1.O12, U1.O13, U1.O15, U1.P12, U3.18, VDD1.2.P$1
VDD1.8: C11.2, C31.1, C32.1, C33.1, C34.1, CL12.1, CL12.2, L2.1, R18.1, U1.D7, U1.D9, U1.D10, U1.D12, U1.D13, U1.D15, U2.J4, U2.J5, U3.21, VDD1.8.P$1
VDD3.3: C3.1, C5.1, C9.1, C35.1, C36.1, C37.1, C38.1, C39.1, C40.1, C45.2, C46.1, C47.1, C48.1, C49.1, C50.1, C51.1, C84.2, C88.1, C100.2, CL13.1, CL13.2, CL60.1, CL60.2, DA7.2, L3.P$1, P.1.1, P.2.8, P.10.16, R5.2, R9.2, R15.2, R23.2, R40.2, R77.1, SL1.P$2, U1.D5, U1.D6, U1.E16, U1.F4, U1.G16, U1.H16, U1.I5, U1.J16, U1.K16, U1.L5, U1.M16, U1.N5, U1.N16, U1.O5, U1.O7, U1.P3, U1.P9, U1.P10, U1.P14, U1.P15, U1.P16, U1.S3, U1.T2, U3.25, U3.27, U3.44, U6.1, U6.9, U6.10, U11.1, VDD3.3.P$1
VDD5: C6.2, C14.1, C94.1, P.3.3, P.4.3, R3.2, R7.2, R62.2, VDD5.P$1
VDD10: C72.2, CL15.1, CL15.2, DA3.2, P.3.2, P.4.2, R25.1, VDD10.P$1
VDD-5: CL17.1, CL17.2, P.3.1, P.4.1, Q10.3, R25.2, R34.1, VDD-5.P$1
VDET: C96.2, C99.1, C107.2, D6.A, D7.C, F2.2, Q5.4, R55.2, U3.9, VDET.P$1
VGND: EM10.4, P.9.-, P.9.S1, P.9.S2, P.9.S3, P.9.S4, VGND.P$1
VIN: F1.2, P.9.+, VIN.P$1
VSHD: C4.1, C13.1, C75.2, L4.1, P.3.5, P.3.32, P.4.5, P.4.32, U3.28, VSHD.P$1
WB2: C97.2, P.10.27, SL1.P$1, WB2.P$1
WRB: CL2.1, CL2.2, P.1.3, U1.E19
X+: EM1.7, P.6.3, X+.P$1
X-: EM1.3, P.6.1, X-.P$1
Y+: EM1.5, P.6.4, Y+.P$1
Y-: EM1.1, P.6.2, Y-.P$1
